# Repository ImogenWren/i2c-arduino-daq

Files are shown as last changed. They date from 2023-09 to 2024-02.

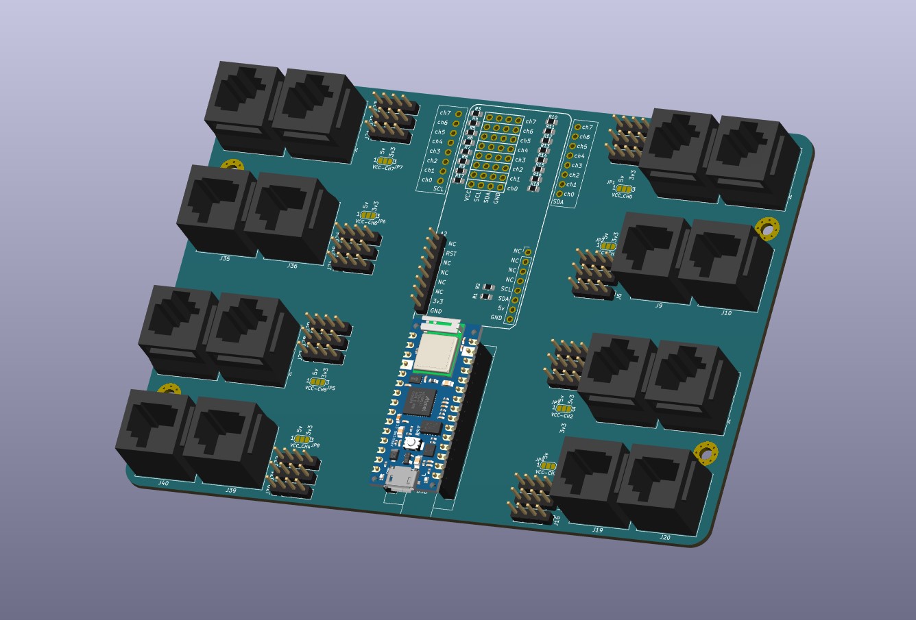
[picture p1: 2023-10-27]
i2c-sensor-breakout-pcb/euro-project-pcb-layout-one.jpg

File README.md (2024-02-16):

# i2c Sensor Breakout Board for Data Aquisition Tasks
Flexible system for gathering i2c sensor data and providing sources to Data Aquisition software (LabVIEW, Python, Matlab, Terra Term, etc)

_The included firmware shows how to wrap up any external sensor library into a flexible format that allows easy modification to existing system and easy addition of 
new sensors._

_PCB Developed for use with Senserion i2c sensors, though is compatable with any i2c enabled periferal devices_

- Data output in CSV format over USB Serial connection as MVP for communications or logging with external software
- Could be improved by the addition of ModBus or JSON formatted data communication with error checking

## PCB



## Hardware Required
- Arduino Nano (PCB designed for this footprint, but other Arduino boards are compatable)
	- SDA A4
	- SCL A5
	
- DAQ (Data AQuisition) PCB
- Logging software
- USB port

## Sensirion SCD41 - CO2 Sensor - i2c
 - 5v or 3.3v

## Sensirion SEK-STC31 - CO2 Sensor - i2c

- 5v or 3.3v (calibrated for 3.3v)

 - Pinout: 
	- Vdd: brown    green
	- SCL: green    brown
	- GND: pink 	pink
	- SDA: yellow	Yellow
 
# Everything LabView

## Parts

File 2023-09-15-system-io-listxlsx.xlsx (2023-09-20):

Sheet: ListOfPoweredComponents
Area | Area Code | Description | Component Type | Component Code | Number Installed | Supplier | Manufacturer | Link to product | Country | Model | Acquired/To Order | Cost [£] | Voltage In | AC/DC | Rated Power [W] | Signal/Current [A] | NC/NO/Latching | Note | How long [s] it receives power
Removal Area α | RAα | Fan adsorption | Fan | FADS | 1 | Farnell | SANYO DENKI | https://uk.farnell.com/sanyo-denki/9cra0412p4k03/fan-c-rotating-40x40x48mm-12v/dp/1907869 | Philippines | 9CRA0412P4K03 | Acquired | 53.172 | 12 | DC | 21.6 | 1.6 |  | 21.6 W rated; 1.6 A; Axial Fan | 540
Removal Area α | RAα | Fan desorption | Fan | FDES | 1 | Farnell | SANYO DENKI | https://uk.farnell.com/sanyo-denki/9cra0412p4k03/fan-c-rotating-40x40x48mm-12v/dp/1907869 | Philippines | 9CRA0412P4K03 | Acquired | 53.172 | 12 | DC | 21.6 | 1.6 |  | 21.6 W rated; 1.6 A; Axial Fan | 360
Removal Area α | RAα | Fan regeneration | Fan | FREG | 1 | Farnell | SANYO DENKI | https://uk.farnell.com/sanyo-denki/9cra0412p4k03/fan-c-rotating-40x40x48mm-12v/dp/1907869 | Philippines | 9CRA0412P4K03 | Acquired | 53.172 | 12 | DC | 21.6 | 1.6 |  | 21.6 W rated; 1.6 A; Axial Fan | 300
Removal Area α | RAα | Butterfly valve 1 before contactor | Butterfly Valve | BV1 | 1 | T7 Design | T7 Design | https://www.t7design.co.uk/electric-hvac-butterfly-valve-68a-ac6-54f.html | UK | Diameter 40mm | Acquired | 50 | 6-24 | DC | 12.00 | 1.0 |  | need a reversing polarity rocker switch to open and close | closing/opening time MAX 5s
Removal Area α | RAα | Buttrefly valve 2 after contactor | Butterfly Valve | BV2 | 1 | T7 Design | T7 Design | https://www.t7design.co.uk/electric-hvac-butterfly-valve-68a-ac6-54f.html | UK | Diameter 40mm | Acquired | 50 | 6-24 | DC | 12.00 | 1.0 |  | need a reversing polarity rocker switch to open and close | closing/opening time MAX 5s
Removal Area α | RAα | Buttrefly valve 3 for water collector adsorption | Butterfly Valve | BV3 | 1 | T7 Design | T7 Design | https://www.t7design.co.uk/electric-hvac-butterfly-valve-68a-ac6-54f.html | UK | Diameter 40mm | Acquired | 50 | 6-24 | DC | 12.00 | 1.0 |  | need a reversing polarity rocker switch to open and close | closing/opening time MAX 5s
Removal Area α | RAα | Buttrefly valve 4 for CO2 collector adsorption | Butterfly Valve | BV4 | 1 | T7 Design | T7 Design | https://www.t7design.co.uk/electric-hvac-butterfly-valve-68a-ac6-54f.html | UK | Diameter 40mm | Acquired | 50 | 6-24 | DC | 12.00 | 1.0 |  | In alternative to V2. Need a reversing polarity rocker switch to open and close | closing/opening time MAX 5s
Removal Area α | RAα | Buttrefly valve 5 for water collector desorption | Butterfly Valve | BV5 | 1 | T7 Design | T7 Design | https://www.t7design.co.uk/electric-hvac-butterfly-valve-68a-ac6-54f.html | UK | Diameter 14 mm* (3D printed) | To Print | 50 | 6-24 | DC | 12.00 | 1.0 |  | In alternative to V4. Need a reversing polarity rocker switch to open and close | closing/opening time MAX 5s
Removal Area α | RAα | Buttrefly valve 6 for CO2 collector desorption - connection with desorption trains | Butterfly Valve | BV6 | 1 | T7 Design | T7 Design | https://www.t7design.co.uk/electric-hvac-butterfly-valve-68a-ac6-54f.html | UK | Diameter 14 mm* (3D printed) | To Print | 50 | 6-24 | DC | 12.00 | 1.0 |  | In alternative to V1. Need a reversing polarity rocker switch to open and close | closing/opening time MAX 5s
Removal Area α | RAα | Substitution Butterfly valve for V3 | Butterfly Valve | BV7 | 1 | T7 Design | T7 Design | https://www.t7design.co.uk/electric-hvac-butterfly-valve-68a-ac6-54f.html | UK | Diameter 40mm | Ordered | 50 | 6-24 | DC | 12.00 | 1.0 |  | In alternative to V3. Need a reversing polarity rocker switch to open and close | closing/opening time MAX 5s
Removal Area α | RAα | Isolation Valve before Water Collector | Solenoid Valve | V2 | 1 | Duncan Rogers | ASCO | https://www.emerson.com/en-us/catalog/automation-solutions/fluid-control-pneumatics?fetchFacets=true | UK | 8210P095 | To Order |  | 10.4-26.4 | DC | 1.20 | 1.0 | NC | OPTIONAL.3/4"; Normally Closed (close when powered); 1.2W; Low Power ASCO Solenoid Valve -Electronically Enhanced Solenoid Valves- Next Gen Series; Internal Material FKM | 780
Removal Area α | RAα | Discharge Valve Water Collector | Solenoid Valve | V4 | 1 | Duncan Rogers | ASCO | https://www.emerson.com/en-us/catalog/automation-solutions/fluid-control-pneumatics?fetchFacets=true | UK | 8210P035 | To Order |  | 10.4-26.4 | DC | 1.20 | 1.0 | NO | OPTIONAL. 3/4"; Normally Open (open when powered); 1.2W; Low Power ASCO Solenoid Valve; Low Power ASCO Solenoid Valve -Electronically Enhanced Solenoid Valves- Next Gen Series; Internal Material FKM | 300
Removal Area α | RAα | Isolation Valve before CO2 Collector | Solenoid Valve | V1 | 1 | Duncan Rogers | ASCO | https://www.emerson.com/en-us/catalog/automation-solutions/fluid-control-pneumatics?fetchFacets=true | UK | 8210P095 | To Order |  | 10.4-26.4 | DC | 1.20 | 1.0 | NC | OPTIONAL. 3/4"; Normally Closed (close when powered); 1.2W; Low Power ASCO Solenoid Valve -Electronically Enhanced Solenoid Valves- Next Gen Series; Internal Material FKM | 780
Removal Area α | RAα | Connection Valve from CO2 Collector to compression trains | Solenoid Valve | V3 | 1 | Duncan Rogers | ASCO | https://www.emerson.com/en-us/catalog/automation-solutions/fluid-control-pneumatics?fetchFacets=true | UK | 8210P095 | To Order |  | 10.4-26.4 | DC | 1.20 | 1.0 | NC | OPTIONAL. 3/4"; Normally Closed (close when powered); 1.2W; Low Power ASCO Solenoid Valve -Electronically Enhanced Solenoid Valves- Next Gen Series; Internal Material FKM | 900
Compressor Train A | CTA | Fan compression | Fan | FCOMP | 1 | Farnell | SANYO DENKI | https://uk.farnell.com/sanyo-denki/9cra0412p4k03/fan-c-rotating-40x40x48mm-12v/dp/1907869 | Philippines | 9CRA0412P4K03 | Acquired | 53.172 | 12 | DC | 21.6 | 1.6 |  | 21.6 W rated; 1.6 A; Axial Fan
Compressor Train A | CTA | Equilibration Valve between Compressor 1 and 2 | Solenoid Valve | VCA1 | 1 | Duncan Rogers | ASCO | https://www.emerson.com/en-us/catalog/automation-solutions/fluid-control-pneumatics?fetchFacets=true | UK | 8210P095 | Acquired |  | 10.4-26.4 | DC | 1.20 | 1.0 | NC | 3/4"; Normally Closed (close when powered); 1.2W; Low Power ASCO Solenoid Valve -Electronically Enhanced Solenoid Valves- Next Gen Series; Internal Material FKM | 600
Compressor Train A | CTA | Discharge valve between Compressor 2 and Fan Compression | Solenoid Valve | VCA3 | 1 | Duncan Rogers | ASCO | https://www.emerson.com/en-us/catalog/automation-solutions/fluid-control-pneumatics?fetchFacets=true | UK | 8262R077 | Acquired |  | 10.4-26.4 | DC | 1.20 | 1.0 | NC | 1/8"; Normally Closed (close when powered); 1.2W; Low Power ASCO Solenoid Valve -Electronically Enhanced Solenoid Valves- Next Gen Series; Internal Material FKM | 1140
Compressor Train A | CTA | Discharge valve after Compressor 2 | Solenoid Valve | VCA5 | 1 | Duncan Rogers | ASCO | https://www.emerson.com/en-us/catalog/automation-solutions/fluid-control-pneumatics?fetchFacets=true | UK | 8262R129 | Acquired |  | 10.4-26.4 | DC | 1.20 | 1.0 | NO | 1/8"; Normally Open (open when powered); 1.2W; Low Power ASCO Solenoid Valve -Electronically Enhanced Solenoid Valves- Next Gen Series; Internal Material FKM | 60
Compressor Train A | CTA | Discharge valve Compression 1 | Butterfly Valve | VCA7 | 1 | T7 Design | T7 Design | https://www.t7design.co.uk/electric-hvac-butterfly-valve-68a-ac6-54f.html | UK | Diameter 14 mm* (3D printed) | To Print | 50 | 6-24 | DC | 12.00 | 1.0
Compressor Train B | CTB | Isolation Valve before Compressor 1 | Solenoid Valve | VCB1 | 1 | Duncan Rogers | ASCO | https://www.emerson.com/en-us/catalog/automation-solutions/fluid-control-pneumatics?fetchFacets=true | UK | 8210P095 | To Order |  | 10.4-26.4 | DC | 1.20 | 1.0 | NC | 3/4"; Normally Closed (close when powered); 1.2W; Low Power ASCO Solenoid Valve -Electronically Enhanced Solenoid Valves- Next Gen Series; Internal Material FKM | 600
Compressor Train B | CTB | Equilibriation Valve between Compressor 1 and 2 | Solenoid Valve | VCB3 | 1 | Duncan Rogers | ASCO | https://www.emerson.com/en-us/catalog/automation-solutions/fluid-control-pneumatics?fetchFacets=true | UK | 8262R077 | To Order |  | 10.4-26.4 | DC | 1.20 | 1.0 | NC | 1/8"; Normally Closed (close when powered); 1.2W; Low Power ASCO Solenoid Valve -Electronically Enhanced Solenoid Valves- Next Gen Series; Internal Material FKM | 1140
Compressor Train B | CTB | Discharge valve after Compressor 2 | Solenoid Valve | VCB5 | 1 | Duncan Rogers | ASCO | https://www.emerson.com/en-us/catalog/automation-solutions/fluid-control-pneumatics?fetchFacets=true | UK | 8262R129 | To Order |  | 10.4-26.4 | DC | 1.20 | 1.0 | NO | 1/8"; Normally Open (open when powered); 1.2W; Low Power ASCO Solenoid Valve -Electronically Enhanced Solenoid Valves- Next Gen Series; Internal Material FKM | 60
Compressor Train B | CTB | Discharge valve Compression 1 | Solenoid Valve | VCB7 | 1 | Duncan Rogers | ASCO | https://www.emerson.com/en-us/catalog/automation-solutions/fluid-control-pneumatics?fetchFacets=true | UK | 8210P035 | To Order |  | 10.4-26.4 | DC | 1.20 | 1.0 | NO | 3/4"; Normally Open (open when powered); 1.2W; Low Power ASCO Solenoid Valve; Low Power ASCO Solenoid Valve -Electronically Enhanced Solenoid Valves- Next Gen Series; Internal Material FKM | 60
Heating and Cooling | H&C | Pump water regenerative heat exchangers loop | Pump | PWR | 1 | RS COMPONENTS | RS | https://uk.rs-online.com/web/p/water-pumps/8170772 | UK | M510M; RS Stock Number 8170772 | To Order | 130.96 | 12 | DC | 15.0 | 1.0 |  | OPTIONAL. MAX 8litre/min; MAX 580mbar; Requires RS Eqi-V2M Brushless controller (RS Stock No. 125-3571, https://uk.rs-online.com/web/p/pump-controllers/1253571) | 360
Heating and Cooling | H&C | Pump Heating Water Loop | Pump | PWH | 1 | RS COMPONENTS | RS | https://uk.rs-online.com/web/p/water-pumps/8170772 | UK | M510M; RS Stock Number 8170772 | Acquired | 130.96 | 12 | DC | 15.0 | 1.0 |  | MAX 8litre/min; MAX 580mbar; Requires RS Eqi-V2M Brushless controller (RS Stock No. 125-3571, https://uk.rs-online.com/web/p/pump-controllers/1253571) | 360
Heating and Cooling | H&C | Pump Cooling Water Loop | Pump | PWC | 1 | RS COMPONENTS | RS | https://uk.rs-online.com/web/p/water-pumps/8170772 | UK | M510M; RS Stock Number 8170772 | To Order | 130.96 | 12 | DC | 15.0 | 1.0 |  | MAX 8litre/min; MAX 580mbar; Requires RS Eqi-V2M Brushless controller (RS Stock No. 125-3571, https://uk.rs-online.com/web/p/pump-controllers/1253571) | 360
Heating and Cooling | H&CA | Pump Thermal Wave 1 | Pump | PTWA | 1 | RS COMPONENTS | RS | https://uk.rs-online.com/web/p/water-pumps/8170772 | UK | M510M; RS Stock Number 8170772 | To Order | 130.96 | 12 | DC | 15.0 | 1.0 |  | MAX 8litre/min; MAX 580mbar; Requires RS Eqi-V2M Brushless controller (RS Stock No. 125-3571, https://uk.rs-online.com/web/p/pump-controllers/1253571) | 1200
Heating and Cooling | H&CA | Solenoid Valve Thermal Wave 1 | Solenoid Valve | VTWA1 | 1 | CONNEXION DEVELOPMENTS LTD | RPE Srl | https://solenoid-valve.world/product/898/rpe-srl/8mm-push-fit-water-solenoid-valve-02-10bar-nylon-6v-latching-1145bb | Italy | 1145BB | To Order | 35.5 | 12 | DC | 2.25 | 0.375 | Latching | 6 or 12vDC 2.25Watts 375mA
Heating and Cooling | H&CA | Solenoid Valve Thermal Wave 2 | Solenoid Valve | VTWA2 | 1 | CONNEXION DEVELOPMENTS LTD | RPE Srl | https://solenoid-valve.world/product/898/rpe-srl/8mm-push-fit-water-solenoid-valve-02-10bar-nylon-6v-latching-1145bb | Italy | 1145BB | To Order | 35.5 | 12 | DC | 2.25 | 0.375 | Latching | 6 or 12vDC 2.25Watts 375mA
Heating and Cooling | H&CA | Solenoid Valve Thermal Wave 3 | Solenoid Valve | VTWA3 | 1 | CONNEXION DEVELOPMENTS LTD | RPE Srl | https://solenoid-valve.world/product/898/rpe-srl/8mm-push-fit-water-solenoid-valve-02-10bar-nylon-6v-latching-1145bb | Italy | 1145BB | To Order | 35.5 | 12 | DC | 2.25 | 0.375 | Latching | 6 or 12vDC 2.25Watts 375mA
Heating and Cooling | H&CA | Solenoid Valve Thermal Wave 4 | Solenoid Valve | VTWA4 | 1 | CONNEXION DEVELOPMENTS LTD | RPE Srl | https://solenoid-valve.world/product/898/rpe-srl/8mm-push-fit-water-solenoid-valve-02-10bar-nylon-6v-latching-1145bb | Italy | 1145BB | To Order | 35.5 | 12 | DC | 2.25 | 0.375 | Latching | 6 or 12vDC 2.25Watts 375mA
Heating and Cooling | H&CB | Pump Thermal Wave 1 | Pump | PTWB | 1 | RS COMPONENTS | RS | https://uk.rs-online.com/web/p/water-pumps/8170772 | UK | M510M; RS Stock Number 8170772 | To Order | 130.96 | 12 | DC | 15.0 | 1.0 |  | MAX 8litre/min; MAX 580mbar; Requires RS Eqi-V2M Brushless controller (RS Stock No. 125-3571, https://uk.rs-online.com/web/p/pump-controllers/1253571) | 1200
Heating and Cooling | H&CB | Solenoid Valve Thermal Wave 1 | Solenoid Valve | VTWB1 | 1 | CONNEXION DEVELOPMENTS LTD | RPE Srl | https://solenoid-valve.world/product/898/rpe-srl/8mm-push-fit-water-solenoid-valve-02-10bar-nylon-6v-latching-1145bb | Italy | 1145BB | To Order | 35.5 | 12 | DC | 2.25 | 0.375 | Latching | 6 or 12vDC 2.25Watts 375mA
Heating and Cooling | H&CB | Solenoid Valve Thermal Wave 2 | Solenoid Valve | VTWB2 | 1 | CONNEXION DEVELOPMENTS LTD | RPE Srl | https://solenoid-valve.world/product/898/rpe-srl/8mm-push-fit-water-solenoid-valve-02-10bar-nylon-6v-latching-1145bb | Italy | 1145BB | To Order | 35.5 | 12 | DC | 2.25 | 0.375 | Latching | 6 or 12vDC 2.25Watts 375mA
Heating and Cooling | H&CB | Solenoid Valve Thermal Wave 3 | Solenoid Valve | VTWB3 | 1 | CONNEXION DEVELOPMENTS LTD | RPE Srl | https://solenoid-valve.world/product/898/rpe-srl/8mm-push-fit-water-solenoid-valve-02-10bar-nylon-6v-latching-1145bb | Italy | 1145BB | To Order | 35.5 | 12 | DC | 2.25 | 0.375 | Latching | 6 or 12vDC 2.25Watts 375mA
Heating and Cooling | H&CB | Solenoid Valve Thermal Wave 4 | Solenoid Valve | VTWB4 | 1 | CONNEXION DEVELOPMENTS LTD | RPE Srl | https://solenoid-valve.world/product/898/rpe-srl/8mm-push-fit-water-solenoid-valve-02-10bar-nylon-6v-latching-1145bb | Italy | 1145BB | To Order | 35.5 | 12 | DC | 2.25 | 0.375 | Latching | 6 or 12vDC 2.25Watts 375mA
 |  |  | Total Digital Out | 35 |  |  |  |  |  |  |  |  |  |  | 288.6 | 33.4
 |  |  |  |  |  |  |  |  |  |  |  |  |  |  | Power Needed | Current Needed

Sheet: ListOfSensors
Area | Area Code | Description | Component Type | Component Code | DAQ Module | Channel | Units Installed | Supplier | Manufacturer | Link to product | Country | Model | Acquired/To Order | Cost [£] | Voltage In [V] | Current In [mA] | AC/DC | MAX Power [W] | Analogue/Digital | Signal Type | Signal Range | Note
Removal Area α | RAα | ΔP Sensor across FADS | Pressure Differential Sensor | ΔP1 | NI 9201 B | 0 | 1 | Farnell | Sensirion | https://uk.farnell.com/sensirion/sdp816-125pa/pressure-sensor-analogue-125pa/dp/2886667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 | Switzerland | SDP816-125PA | Acquired | 28.4 | 2.7-5.5 | 0.0055 | DC | 0.03025 | Analogue Ratiometric | Voltage | 10%-90% of Supply Voltage
Removal Area α | RAα | ΔP Sensor across FDES | Pressure Differential Sensor | ΔP2 | NI 9201 B | 1 | 1 | Farnell | Sensirion | https://uk.farnell.com/sensirion/sdp816-500pa/pressure-sensor-analogue-500pa/dp/2886668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 | Switzerland | SDP816-500PA | Acquired | 28.4 | 2.7-5.5 | 0.0055 | DC | 0.03025 | Analogue Ratiometric | Voltage | 10%-90% of Supply Voltage
Removal Area α | RAα | ΔP Sensor across FREG | Pressure Differential Sensor | ΔP3 | NI 9201 B | 2 | 1 | Farnell | Sensirion | https://uk.farnell.com/sensirion/sdp816-500pa/pressure-sensor-analogue-500pa/dp/2886668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 | Switzerland | SDP816-500PA | Acquired | 28.4 | 2.7-5.5 | 0.0055 | DC | 0.03025 | Analogue Ratiometric | Voltage | 10%-90% of Supply Voltage
Removal Area α | RAα | CO2, RH and T sensor before contactor | Carbon Dioxide, Relative Humidity and Temperature Sensor | CD1 | NI 9402 |  | 1 | Farnell | Sensirion | https://uk.farnell.com/sensirion/sek-scd41-sensor/development-board-co2-sensor/dp/3677907?ost=sek-scd+41 | Switzerland | SEK-SCD41 | Aquired | 103 | 2.4-5.5 |  | DC |  | Digital |  |  | I2C communication protocol
Removal Area α | RAα | CO2, RH and T sensor after contactor | Carbon Dioxide, Relative Humidity and Temperature Sensor | CD2 | NI 9402 |  | 1 | Farnell | Sensirion | https://uk.farnell.com/sensirion/sek-scd41-sensor/development-board-co2-sensor/dp/3677907?ost=sek-scd+41 | Switzerland | SEK-SCD41 | Aquired | 103 | 2.4-5.5 |  | DC |  | Digital |  |  | I2C communication protocol
Removal Area α | RAα | CO2 Sensor before collectors | Carbon Dioxide Sensor | CD3 | NI 9402 | ? | 1 | Farnell | Sensirion | https://uk.farnell.com/sensirion/sek-stc31/eval-kit-co2-sensor/dp/3804234?st=co2%20sensor | Switzerland | SEK-STC31 | To Order | 59.7 | 3.3 | 0.005 | DC | 0.03025 | Digital |  |  | I2C communication protocol
Removal Area α | RAα | CO2 Sensor after collectors | Carbon Dioxide Sensor | CD4 | NI 9402 | ? | 1 | Farnell | Sensirion | https://uk.farnell.com/sensirion/sek-stc31/eval-kit-co2-sensor/dp/3804234?st=co2%20sensor | Switzerland | SEK-STC31 | To Order | 59.7 | 3.3 | 0.005 | DC | 0.03025 | Digital |  |  | I2C communication protocol
Removal Area α | RAα | CO2 Sensor after water collector | Carbon Dioxide Sensor | CD5 | NI 9402 | ? | 1 | Farnell | Sensirion | https://uk.farnell.com/sensirion/sek-stc31/eval-kit-co2-sensor/dp/3804234?st=co2%20sensor | Switzerland | SEK-STC31 | To Order | 59.7 | 3.3 | 0.005 | DC | 0.03025 | Digital |  |  | I2C communication protocol
Removal Area α | RAα | CO2 Sensor after CO2 collector | Carbon Dioxide Sensor | CD6 | NI 9402 | ? | 1 | Farnell | Sensirion | https://uk.farnell.com/sensirion/sek-stc31/eval-kit-co2-sensor/dp/3804234?st=co2%20sensor | Switzerland | SEK-STC31 | To Order | 59.7 | 3.3 | 0.005 | DC | 0.03025 | Digital |  |  | I2C communication protocol
Removal Area α | RAα |  | Relative Humidity and Temperature Sensor | RHT1 | NI 9402 | ? | 1 | Farnell | Sensirion | https://uk.farnell.com/sensirion/sek-sht45-ad1b-sensors/evaluation-kit-temp-humidity-sensor/dp/3958229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 | Switzerland | SEK-SHT45 | Ordered | 32.3 | 1.08-3.6 | 0.002 | DC | 0.2 | Digital |  |  | I2C communication protocol; Each SEK-SHT45 contains 3 sensors but needs the SEK sensor bridge
Removal Area α | RAα |  | Relative Humidity and Temperature Sensor | RHT2 | NI 9402 | ? | 1 | RS | Sensirion | https://uk.rs-online.com/web/p/sensor-development-tools/2365204 | Switzerland | SEK-SHT41I-AD1B | Ordered | 37.47 | 2.3-5.5 | 0.002 | DC | 0.2 | Digital |  |  | I2C communication protocol; Each SEK-SHT41I contains 3 sensors but needs the SEK sensor bridge
Removal Area α | RAα | RH and T Sensor before collectors | Relative Humidity and Temperature Sensor | RHT3 | NI 9402 | ? | 1 | RS | Sensirion | https://uk.rs-online.com/web/p/sensor-development-tools/2365204 | Switzerland | SEK-SHT41I-AD1B | Ordered | 37.47 | 2.3-5.5 | 0.002 | DC | 0.2 | Digital |  |  | I2C communication protocol; Each SEK-SHT41I contains 3 sensors but needs the SEK sensor bridge
Removal Area α | RAα | RH and T Sensor after collectors | Relative Humidity and Temperature Sensor | RHT4 | NI 9402 | ? | 1 | RS | Sensirion | https://uk.rs-online.com/web/p/sensor-development-tools/2365204 | Switzerland | SEK-SHT41I-AD1B | Ordered | 37.47 | 2.3-5.5 | 0.002 | DC | 0.2 | Digital |  |  | I2C communication protocol; Each SEK-SHT41I contains 3 sensors but needs the SEK sensor bridge
Removal Area α | RAα | RH and T Sensor after water collector | Relative Humidity and Temperature Sensor | RHT5 | NI 9402 | ? | 1 | RS | Sensirion | https://uk.rs-online.com/web/p/sensor-development-tools/2365204 | Switzerland | SEK-SHT41I-AD1B | Ordered | 37.47 | 2.3-5.5 | 0.002 | DC | 0.2 | Digital |  |  | I2C communication protocol; Each SEK-SHT41I contains 3 sensors but needs the SEK sensor bridge
Removal Area α | RAα | RH and T Sensor after CO2 collector | Relative Humidity and Temperature Sensor | RHT6 | NI 9402 | ? | 1 | RS | Sensirion | https://uk.rs-online.com/web/p/sensor-development-tools/2365204 | Switzerland | SEK-SHT41I-AD1B | Ordered | 37.47 | 2.3-5.5 | 0.002 | DC | 0.2 | Digital |  |  | I2C communication protocol; Each SEK-SHT41I contains 3 sensors but needs the SEK sensor bridge
Removal Area α | RAα | Current Tranducer FADS | Curent Sensor | CS1 | NI 9201 A | 0 | 1 |  | Seedstudio |  |  |  | Aquired | 5 | 3.3-5 |  | DC | 0.027 | Analogue proportional to current | Voltage |  | ±5A DC/AC Current Sensor; base sensitivity of 200mV/A (approx); | 0-1v
Removal Area α | RAα |  | Curent Sensor | CS1 | NI 9201 A | 0 | 1 | RS/ACTIVE ROBOT | Allegro | https://uk.rs-online.com/web/p/current-sensor-ics/8660767 or https://www.active-robots.com/sparkfun-current-sensor-breakout-acs723-low-current.html |  | ACS723LLCTR-05AB-T or in SparkFun Current Sensor Breakout - ACS723 (Low Current) | Ordered | 5 | 4.5-5.5 | 0.006 | DC | 0.027 | Analogue proportional to current | Voltage |  | ±5A DC/AC Current Sensor; base sensitivity of 200mV/A (approx); Requires a microprocessor board; | 0-1v
Removal Area α | RAα | Current Tranducer FDES | Curent Sensor | CS2 | NI 9201 A | 0 | 1 |  | Seedstudio |  |  |  | Aquired | 5 | 3.3-5 |  | DC | 0.027 | Analogue proportional to current | Voltage |  | ±5A DC/AC Current Sensor; base sensitivity of 200mV/A (approx); | 0-1v
Removal Area α | RAα |  | Curent Sensor | CS2 | NI 9201 A | 1 | 1 | RS/ACTIVE ROBOT | Allegro | https://uk.rs-online.com/web/p/current-sensor-ics/8660767 or https://www.active-robots.com/sparkfun-current-sensor-breakout-acs723-low-current.html |  | ACS723LLCTR-05AB-T or in SparkFun Current Sensor Breakout - ACS723 (Low Current) | Ordered | 5 | 4.5-5.5 | 0.006 | DC | 0.027 | Analogue proportional to current | Voltage |  | ±5A DC/AC Current Sensor; base sensitivity of 400mV/A (approx); Requires a microprocessor board; | 0-1v
Removal Area α | RAα | Current Tranducer FREG | Curent Sensor | CS3 | NI 9201 A | 2 | 1 | RS/ACTIVE ROBOT | Allegro | https://uk.rs-online.com/web/p/current-sensor-ics/8660767 or https://www.active-robots.com/sparkfun-current-sensor-breakout-acs723-low-current.html |  | ACS723LLCTR-05AB-T or in SparkFun Current Sensor Breakout - ACS723 (Low Current) | Ordered | 5 | 4.5-5.5 | 0.006 | DC | 0.027 | Analogue proportional to current | Voltage |  | ±5A DC/AC Current Sensor; base sensitivity of 400mV/A (approx); Requires a microprocessor board; | 0-1v
Removal Area α | RAα | T probe before HEXC-AIR | Thermocouple | T1 | NI 9213 A | 0 | 1 | Farnell | Omega | https://at.farnell.com/en-AT/omega/htmtss-125g-6/thermoelement-typ-t-152-4mm-315/dp/3799164 | United States | HTMTSS-125G-6 | Acquired |  |  |  |  |  |  |  |  | T thermocouple
Removal Area α | RAα |  | Thermocouple | T2 | NI 9213 A | 1 |  |  |  |  |  |  | Acquired |  |  |  |  |  |  |  |  | T thermocouple
Removal Area α | RAα | T probe after HEXC-AIR | Thermocouple | T3 | NI 9213 A | 2 | 1 | Farnell | Omega | https://at.farnell.com/en-AT/omega/htmtss-125g-6/thermoelement-typ-t-152-4mm-315/dp/3799164 | United States | HTMTSS-125G-6 | Acquired |  |  |  |  |  |  |  |  | T thermocouple
Removal Area α | RAα | T probe before HEXH-AIR | Thermocouple | T4 | NI 9213 A | 3 | 1 | Farnell | Omega | https://at.farnell.com/en-AT/omega/htmtss-125g-6/thermoelement-typ-t-152-4mm-315/dp/3799164 | United States | HTMTSS-125G-6 | Acquired |  |  |  |  |  |  |  |  | T thermocouple
Removal Area α | RAα |  | Thermocouple | T5 | NI 9213 A | 4 |  |  |  |  |  |  | Acquired |  |  |  |  |  |  |  |  | Optional. T thermocouple
Removal Area α | RAα | T probe after HEXH-AIR | Thermocouple | T6 | NI 9213 A | 5 | 1 | Farnell | Omega | https://at.farnell.com/en-AT/omega/htmtss-125g-6/thermoelement-typ-t-152-4mm-315/dp/3799164 | United States | HTMTSS-125G-6 | Acquired |  |  |  |  |  |  |  |  | T thermocouple
Removal Area α | RAα | T probe HEXC-WATER in | Thermocouple | TR1 | NI 9213 A | 6 | 1 | RS |  | RS PRO Type K Thermocouple 250mm Length, 3mm Diameter → +1100°C | RS (rs-online.com) (https://uk.rs-online.com/web/p/thermocouples/3971270?gb=s) |  | 397-1270 | Ordered | 28.52 |  |  |  |  |  |  |  | T thermocouple
Removal Area α | RAα | T probe HEXC-WATER out | Thermocouple | TR2 | NI 9213 A | 7 | 1 | RS |  | RS PRO Type K Thermocouple 250mm Length, 3mm Diameter → +1100°C | RS (rs-online.com) (https://uk.rs-online.com/web/p/thermocouples/3971270?gb=s) |  | 397-1270 | Ordered | 28.52 |  |  |  |  |  |  |  | T thermocouple
Removal Area α | RAα | T probe HEXH-WATER in | Thermocouple | TR3 | NI 9213 A | 8 | 1 | RS |  | RS PRO Type K Thermocouple 250mm Length, 3mm Diameter → +1100°C | RS (rs-online.com) (https://uk.rs-online.com/web/p/thermocouples/3971270?gb=s) |  | 397-1270 | Ordered | 28.52 |  |  |  |  |  |  |  | T thermocouple
Removal Area α | RAα | T probe HEXH-WATER out | Thermocouple | TR4 | NI 9213 A | 9 | 1 | RS |  | RS PRO Type K Thermocouple 250mm Length, 3mm Diameter → +1100°C | RS (rs-online.com) (https://uk.rs-online.com/web/p/thermocouples/3971270?gb=s) |  | 397-1270 | Ordered | 28.52 |  |  |  |  |  |  |  | T thermocouple
Compressor Train A | CTA | CO2 Sensor before COMPA1 | Carbon Dioxide Sensor | CDCA1
Compressor Train A | CTA | RH and T Sensor before COMPA1 | Relative Humidity and Temperature Sensor | RHTCA1 |  |  |  |  |  |  |  |  | Acquired
Compressor Train A | CTA | CO2, RH and T sensor before COMPA 2 | Carbon Dioxide, Relative Humidity and Temperature Sensor | CDCA2 |  |  |  | RS | Sensirion | https://uk.rs-online.com/web/p/temperature-humidity-sensor-ics/1720552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 |  |  | Acquired
Compressor Train A | CTA | CO2, RH and T sensor out system | Carbon Dioxide, Relative Humidity and Temperature Sensor | CDCA3 |  |  |  | RS | Sensirion | https://uk.rs-online.com/web/p/temperature-humidity-sensor-ics/1720552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 |  |  | Acquired
Compressor Train A | CTA | T probe after COMPA1 | Thermocouple | TCA1
Compressor Train A | CTA | T probe after COMPA2 | Thermocouple | TCA2
Compressor Train A | CTA | T probe HEXC-WATER in | Thermocouple | TRCA1
Compressor Train A | CTA | T probe HEXC-WATER out | Thermocouple | TRCA2
Compressor Train A | CTA | T probe HEXH-WATER in | Thermocouple | TRCA3
Compressor Train A | CTA | T probe HEXH-WATER out | Thermocouple | TRCA4
Compressor Train A | CTA | Pressure Transducer COMPA1 | Preussure Transducer Compressor A1 | PCA1 | NI 9201 B | 3 | 1 | JWF Process Solutions | WIKA | https://www.wika.com/en-gb/s_20.WIKA?36404=36404_0&36405=36405_0&36406=36406_0&36407=36407_0 |  | A-10 | Ordered | 137 | 8-30 | 0.02 | DC | 0.6 | Analogue | 0-10 V
Compressor Train A | CTA | Pressure Transducer COMPA2 | Preussure Transducer Compressor A2 | PCA2 | NI 9201 B | 4 | 1 | JWF Process Solutions | WIKA | https://www.wika.com/en-gb/s_20.WIKA?36404=36404_0&36405=36405_0&36406=36406_0&36407=36407_0 |  | A-10 | Ordered | 137 | 8-30 | 0.02 | DC | 0.6 | Analogue | 0-10 V
Compressor Train A | CTA | RH and T sensor after COMPA1 | Relative Humidity and Temperature Sensor | CARTH1 | NI 9402 | ? | 1 | Farnell | Sensirion | https://uk.farnell.com/sensirion/sek-sht45-ad1b-sensors/evaluation-kit-temp-humidity-sensor/dp/3958229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 | Switzerland | SEK-SHT41I-AD1B | Ordered | 37.5 | 1.08-3.6 | 0.002 | DC | 0.2 | Digital |  |  | I2C communication protocol; Each SEK-SHT45 contains 3 sensors but needs the SEK sensor bridge
Compressor Train A | CTA | CO2 Sensor after COMPA1 | Carbon Dioxide Sensor | CACD1 | NI 9402 | ? | 1 | RS Components | Sensirion | https://uk.rs-online.com/web/p/sensor-development-tools/2365204 | Switzerland | SEK-STC31 | To Order | 59.7 | 3.3 | 0.005 | DC | 0.03025 | Digital |  |  | I2C communication protocol
Compressor Train B | CTB | Pressure Transducer COMPB1 | Preussure Transducer Compressor B1 | PCB1 | NI 9201 B | 5 | 1 | JWF Process Solutions | WIKA | https://www.wika.com/en-gb/s_20.WIKA?36404=36404_0&36405=36405_0&36406=36406_0&36407=36407_0 |  | A-10 | Ordered | 137 | 8-30 | 0.02 | DC | 0.6 | Analogue | 0-10 V
Compressor Train B | CTB | Pressure Transducer COMPB2 | Preussure Transducer Compressor B2 | PCB2 | NI 9201 B | 6 | 1 | JWF Process Solutions | WIKA | https://www.wika.com/en-gb/s_20.WIKA?36404=36404_0&36405=36405_0&36406=36406_0&36407=36407_0 |  | A-10 | Ordered | 137 | 8-30 | 0.02 | DC | 0.6 | Analogue | 0-10 V
Compressor Train B | CTB | RH and T sensor after COMPB1 | Relative Humidity and Temperature Sensor | CBRTH1 | NI 9402 | ? | 1 | RS Components | Sensirion | https://uk.rs-online.com/web/p/sensor-development-tools/2365204 | Switzerland | SEK-SHT41I-AD1B | Ordered | 37.5 | 1.08-3.6 | 0.002 | DC | 0.2 | Digital |  |  | I2C communication protocol; Each SEK-SHT45 contains 3 sensors but needs the SEK sensor bridge
Compressor Train B | CTB | CO2 Sensor after COMPB1 | Carbon Dioxide Sensor | CBCD1 | NI 9402 | ? | 1 | Farnell | Sensirion | https://uk.farnell.com/sensirion/sek-stc31/eval-kit-co2-sensor/dp/3804234?st=co2%20sensor | Switzerland | SEK-STC31 | To Order | 59.7 | 3.3 | 0.005 | DC | 0.03025 | Digital |  |  | I2C communication protocol
Supply Area | SA | Pressure Transducer GST | Preussure Transducer CO2 Storage | PC | NI 9201 B | 7 | 1 | JWF Process Solutions | WIKA | https://www.wika.com/en-gb/s_20.WIKA?36404=36404_0&36405=36405_0&36406=36406_0&36407=36407_0 |  | A-10 | Ordered | 137 | 8-30 | 0.02 | DC | 0.6 | Analogue | 0-10 V
Supply Area | SA | T probe in GST | Thermocouple in the CO2 Storage | TC | NI 9213 B | 8 | 1 | ESTech Lab | ESTech Lab |  |  |  | Acquired |  |  |  |  |  |  |  |  | T thermocouple
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

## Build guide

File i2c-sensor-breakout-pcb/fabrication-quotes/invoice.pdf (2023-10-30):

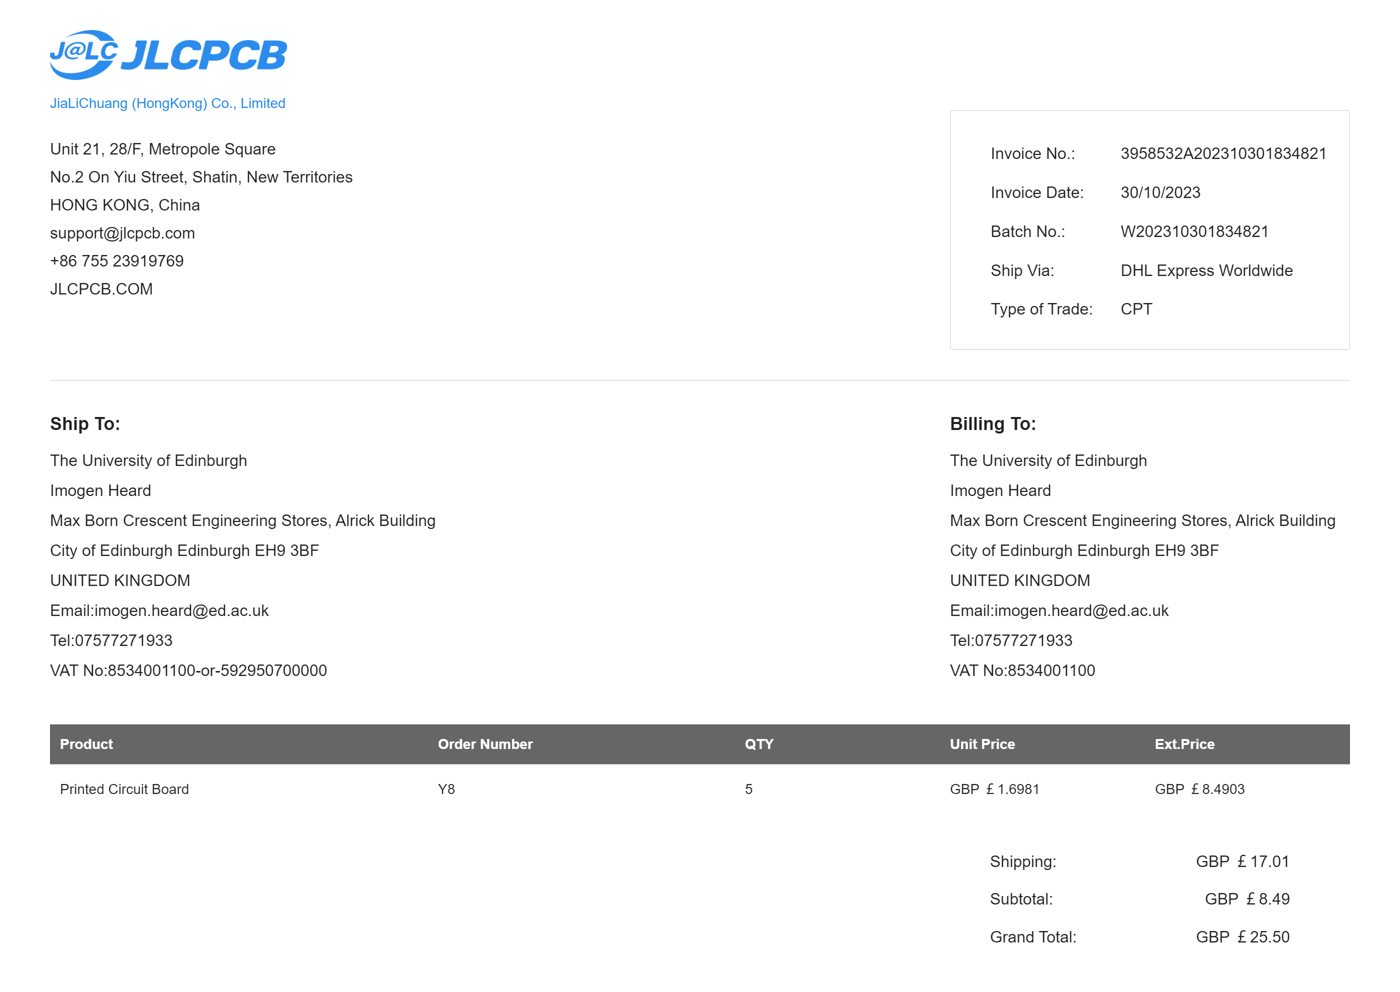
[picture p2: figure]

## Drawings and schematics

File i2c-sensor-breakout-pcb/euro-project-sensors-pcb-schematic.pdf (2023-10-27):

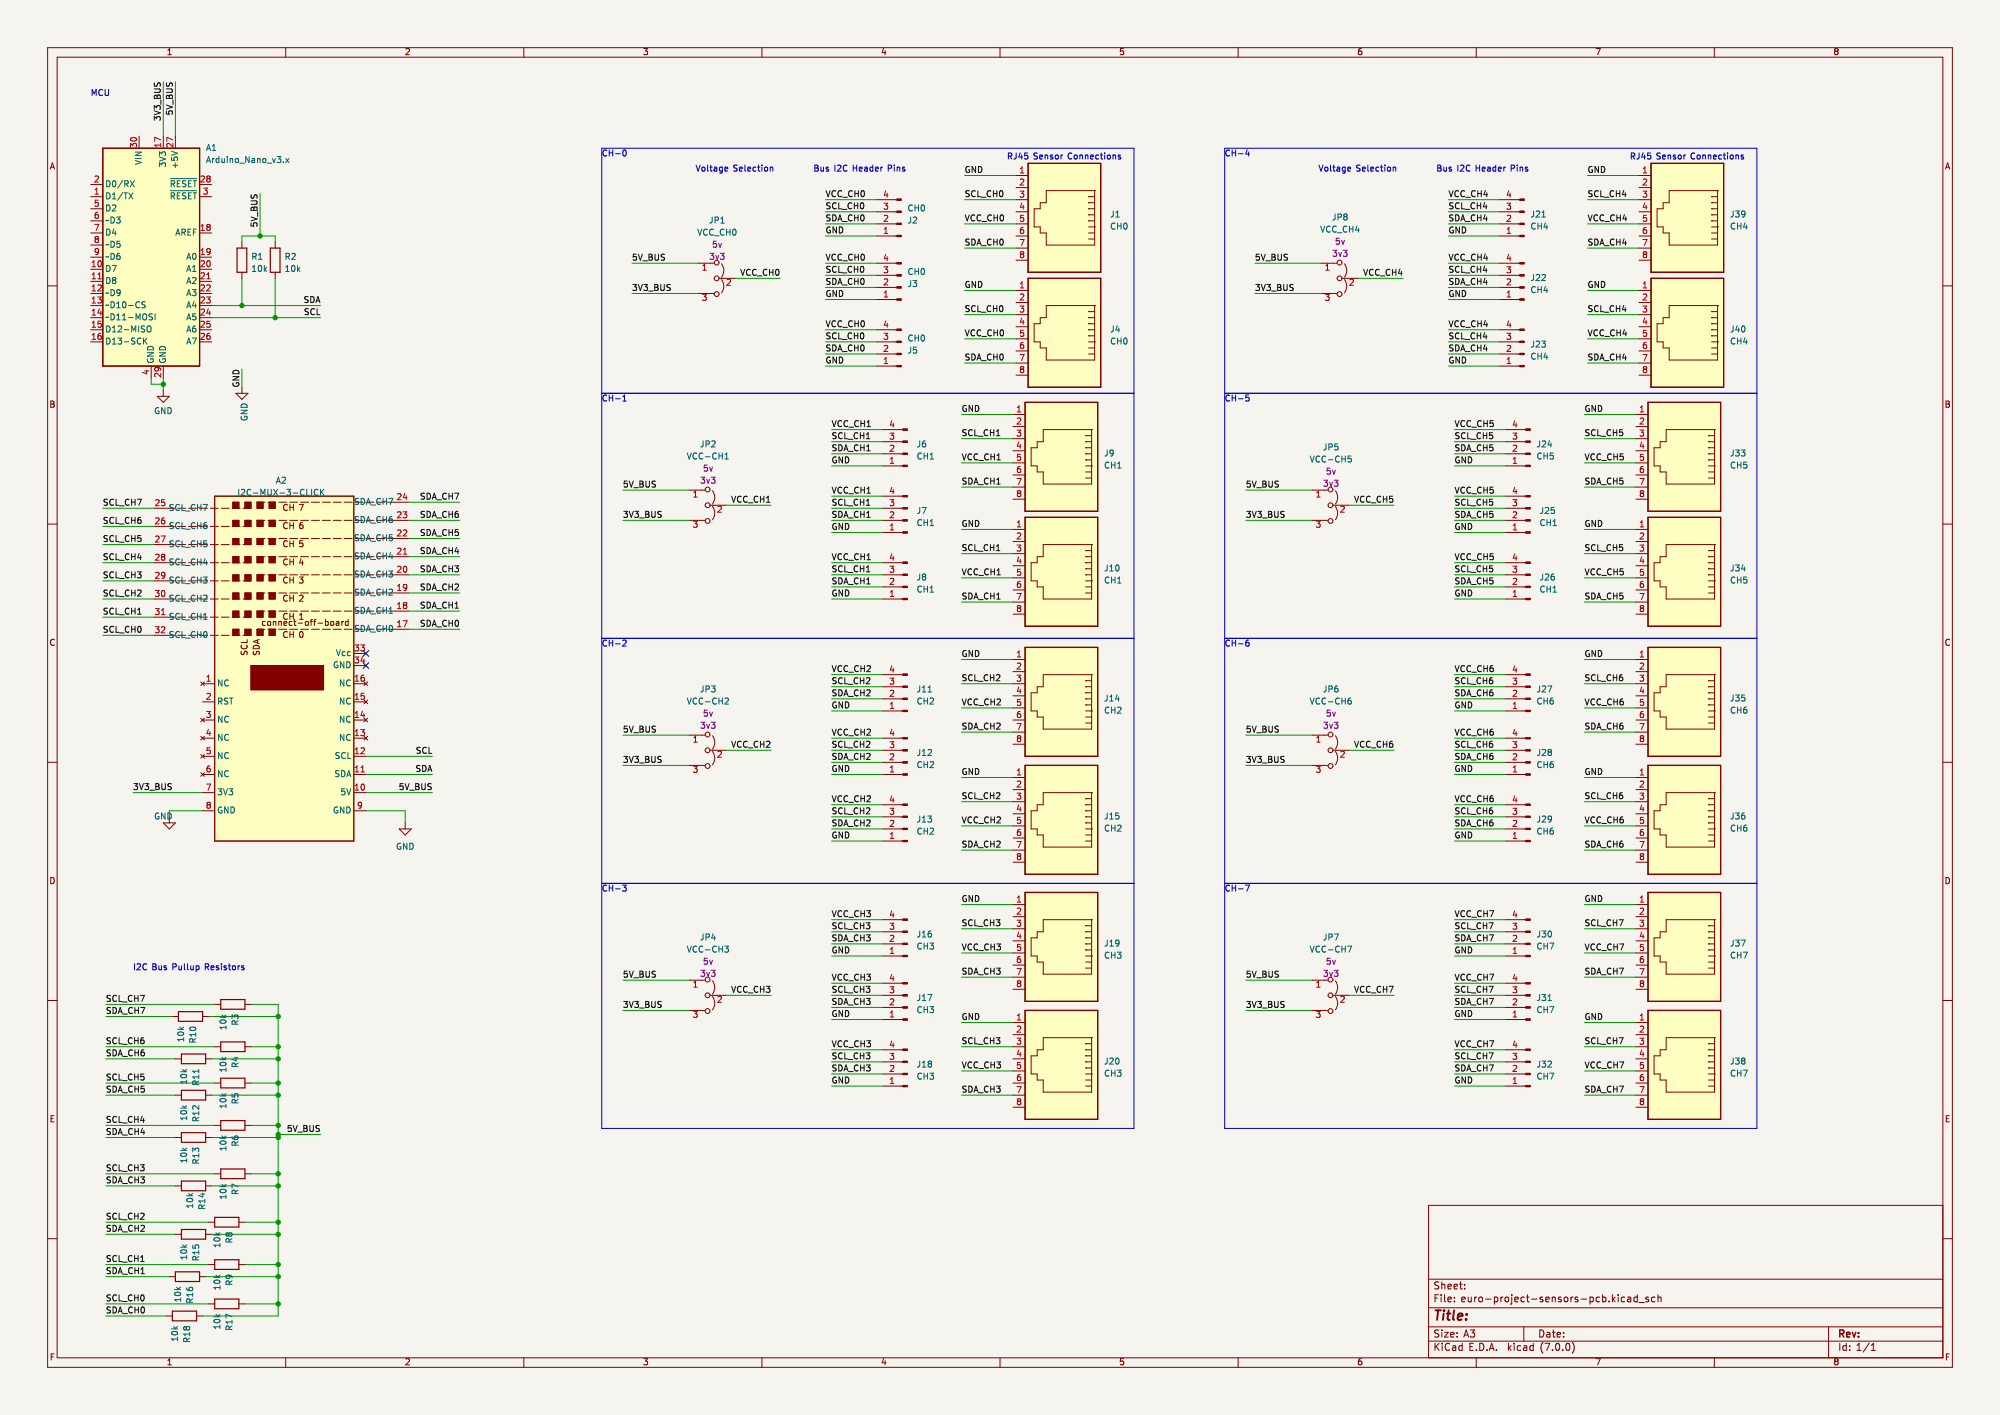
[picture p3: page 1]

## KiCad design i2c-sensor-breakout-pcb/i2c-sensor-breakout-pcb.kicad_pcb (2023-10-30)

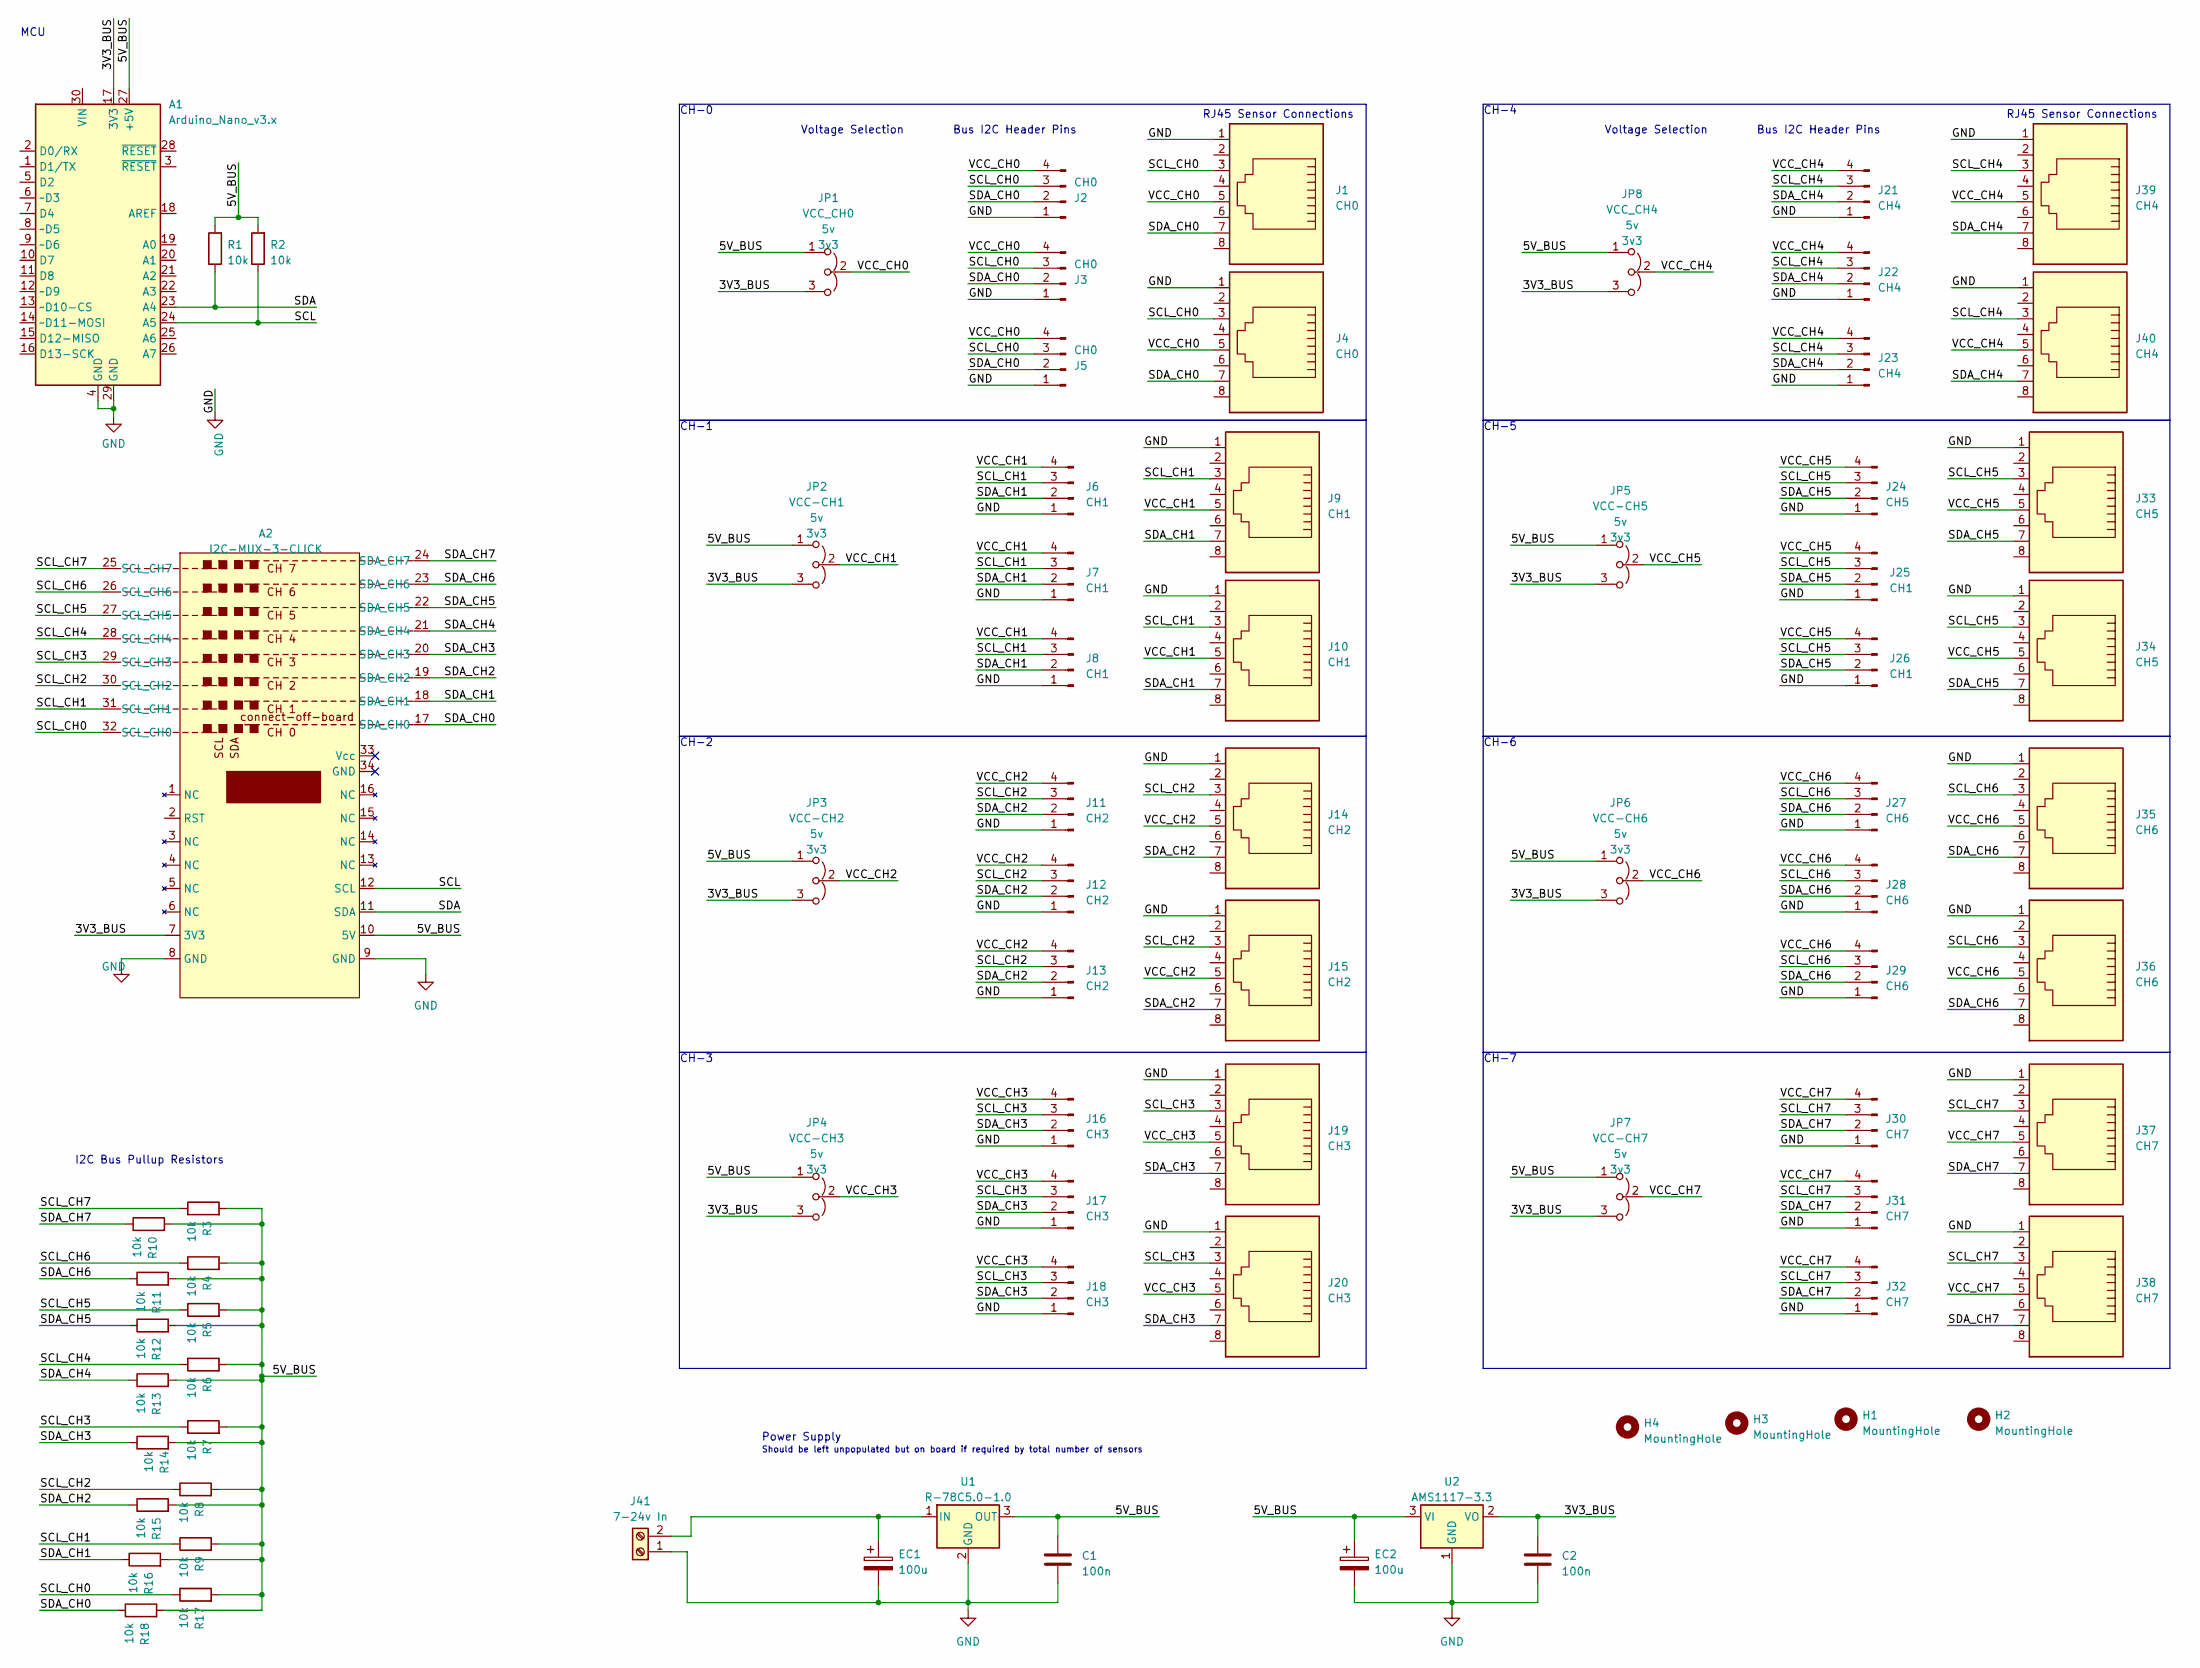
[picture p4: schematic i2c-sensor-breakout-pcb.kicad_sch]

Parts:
A1: Arduino_Nano_v3.x; Arduino_Nano
A2: I2C-MUX-3-CLICK
C1, C2: 100n; C_0805_2012_HandSolder_kawaii; JLCpart C779975
EC1, EC2: 100u; CP_Elec_10x10
H1, H2, H3, H4: MountingHole; MountingHole_3.2mm_M3_Pad_Via
J1, J4: CH0; RJ45_OST_PJ012-8P8CX_Vertical
J2, J3, J5: CH0; PinHeader_1x04_P2.54mm_Vertical
J6, J7, J8, J25, J26: CH1; PinHeader_1x04_P2.54mm_Vertical
J9, J10: CH1; RJ45_OST_PJ012-8P8CX_Vertical
J11, J12, J13: CH2; PinHeader_1x04_P2.54mm_Vertical
J14, J15: CH2; RJ45_OST_PJ012-8P8CX_Vertical
J16, J17, J18: CH3; PinHeader_1x04_P2.54mm_Vertical
J19, J20: CH3; RJ45_OST_PJ012-8P8CX_Vertical
J21, J22, J23: CH4; PinHeader_1x04_P2.54mm_Vertical
J24: CH5; PinHeader_1x04_P2.54mm_Vertical
J27, J28, J29: CH6; PinHeader_1x04_P2.54mm_Vertical
J30, J31, J32: CH7; PinHeader_1x04_P2.54mm_Vertical
J33, J34: CH5; RJ45_OST_PJ012-8P8CX_Vertical
J35, J36: CH6; RJ45_OST_PJ012-8P8CX_Vertical
J37, J38: CH7; RJ45_OST_PJ012-8P8CX_Vertical
J39, J40: CH4; RJ45_OST_PJ012-8P8CX_Vertical
J41: 7-24v In; TerminalBlock_Altech_AK300-2_P5.00mm; JLCpart C918120
JP1: VCC_CH0; SolderJumper-3-open-high-power
JP2: VCC-CH1; SolderJumper-3-open-high-power
JP3: VCC-CH2; SolderJumper-3-open-high-power
JP4: VCC-CH3; SolderJumper-3-open-high-power
JP5: VCC-CH5; SolderJumper-3-open-high-power
JP6: VCC-CH6; SolderJumper-3-open-high-power
JP7: VCC-CH7; SolderJumper-3-open-high-power
JP8: VCC_CH4; SolderJumper-3-open-high-power
R1, R2, R3, R4, R5, R6, R7, R8, R9, R10, R11, R12, R13, R14, R15, R16, R17, R18: 10k; R_0805_2012Metric_Pad1.20x1.40mm_HandSolder; JLCpart C2930231
U1: R-78C5.0-1.0; Converter_DCDC_RECOM_R-78E-0.5_THT
U2: AMS1117-3.3; SOT-223-3_TabPin2; JLCpart C2992570

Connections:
/3V3_BUS: A1.17 (3V3), A2.7 (3V3), C2.1, JP1.3 (B), JP2.3 (B), JP3.3 (B), JP4.3 (B), JP5.3 (B), JP6.3 (B), JP7.3 (B), JP8.3 (B), U2.2 (VO)
/5V_BUS: A1.27 (+5V), A2.10 (5V), C1.1, EC2.1, JP1.1 (A), JP2.1 (A), JP3.1 (A), JP4.1 (A), JP5.1 (A), JP6.1 (A), JP7.1 (A), JP8.1 (A), R1.2, R2.2, R3.2, R4.2, R5.2, R6.2, R7.2, R8.2, R9.2, R10.2, R11.2, R12.2, R13.2, R14.2, R15.2, R16.2, R17.2, R18.2, U1.3 (OUT), U2.3 (VI)
/SCL: A1.24 (A5), A2.12 (SCL), R2.1
/SCL_CH0: A2.32 (SCL_CH0), J1.3, J2.3, J3.3, J4.3, J5.3, R17.1
/SCL_CH1: A2.31 (SCL_CH1), J6.3, J7.3, J8.3, J9.3, J10.3, R9.1
/SCL_CH2: A2.30 (SCL_CH2), J11.3, J12.3, J13.3, J14.3, J15.3, R8.1
/SCL_CH3: A2.29 (SCL_CH3), J16.3, J17.3, J18.3, J19.3, J20.3, R7.1
/SCL_CH4: A2.28 (SCL_CH4), J21.3, J22.3, J23.3, J39.3, J40.3, R6.1
/SCL_CH5: A2.27 (SCL_CH5), J24.3, J25.3, J26.3, J33.3, J34.3, R5.1
/SCL_CH6: A2.26 (SCL_CH6), J27.3, J28.3, J29.3, J35.3, J36.3, R4.1
/SCL_CH7: A2.25 (SCL_CH7), J30.3, J31.3, J32.3, J37.3, J38.3, R3.1
/SDA: A1.23 (A4), A2.11 (SDA), R1.1
/SDA_CH0: A2.17 (SDA_CH0), J1.7, J2.2, J3.2, J4.7, J5.2, R18.1
/SDA_CH1: A2.18 (SDA_CH1), J6.2, J7.2, J8.2, J9.7, J10.7, R16.1
/SDA_CH2: A2.19 (SDA_CH2), J11.2, J12.2, J13.2, J14.7, J15.7, R15.1
/SDA_CH3: A2.20 (SDA_CH3), J16.2, J17.2, J18.2, J19.7, J20.7, R14.1
/SDA_CH4: A2.21 (SDA_CH4), J21.2, J22.2, J23.2, J39.7, J40.7, R13.1
/SDA_CH5: A2.22 (SDA_CH5), J24.2, J25.2, J26.2, J33.7, J34.7, R12.1
/SDA_CH6: A2.23 (SDA_CH6), J27.2, J28.2, J29.2, J35.7, J36.7, R11.1
/SDA_CH7: A2.24 (SDA_CH7), J30.2, J31.2, J32.2, J37.7, J38.7, R10.1
/VCC_CH0: J1.5, J2.4, J3.4, J4.5, J5.4, JP1.2 (C)
/VCC_CH1: J6.4, J7.4, J8.4, J9.5, J10.5, JP2.2 (C)
/VCC_CH2: J11.4, J12.4, J13.4, J14.5, J15.5, JP3.2 (C)
/VCC_CH3: J16.4, J17.4, J18.4, J19.5, J20.5, JP4.2 (C)
/VCC_CH4: J21.4, J22.4, J23.4, J39.5, J40.5, JP8.2 (C)
/VCC_CH5: J24.4, J25.4, J26.4, J33.5, J34.5, JP5.2 (C)
/VCC_CH6: J27.4, J28.4, J29.4, J35.5, J36.5, JP6.2 (C)
/VCC_CH7: J30.4, J31.4, J32.4, J37.5, J38.5, JP7.2 (C)
GND: A1.4 (GND), A1.29 (GND), A2.8 (GND), A2.9 (GND), C1.2, C2.2, EC1.2, EC2.2, J1.1, J2.1, J3.1, J4.1, J5.1, J6.1, J7.1, J8.1, J9.1, J10.1, J11.1, J12.1, J13.1, J14.1, J15.1, J16.1, J17.1, J18.1, J19.1, J20.1, J21.1, J22.1, J23.1, J24.1, J25.1, J26.1, J27.1, J28.1, J29.1, J30.1, J31.1, J32.1, J33.1, J34.1, J35.1, J36.1, J37.1, J38.1, J39.1, J40.1, J41.1, U1.2 (GND), U2.1 (GND)
unnamed: EC1.1, J41.2, U1.1 (IN)

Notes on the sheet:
RJ45 Sensor Connections
CH-3
I2C Bus Pullup Resistors
Bus I2C Header Pins
CH-2
Voltage Selection
CH-7
MCU
CH-1
CH-6
Should be left unpopulated but on board if required by total number of sensors
CH-4
Power Supply
CH-0
CH-5

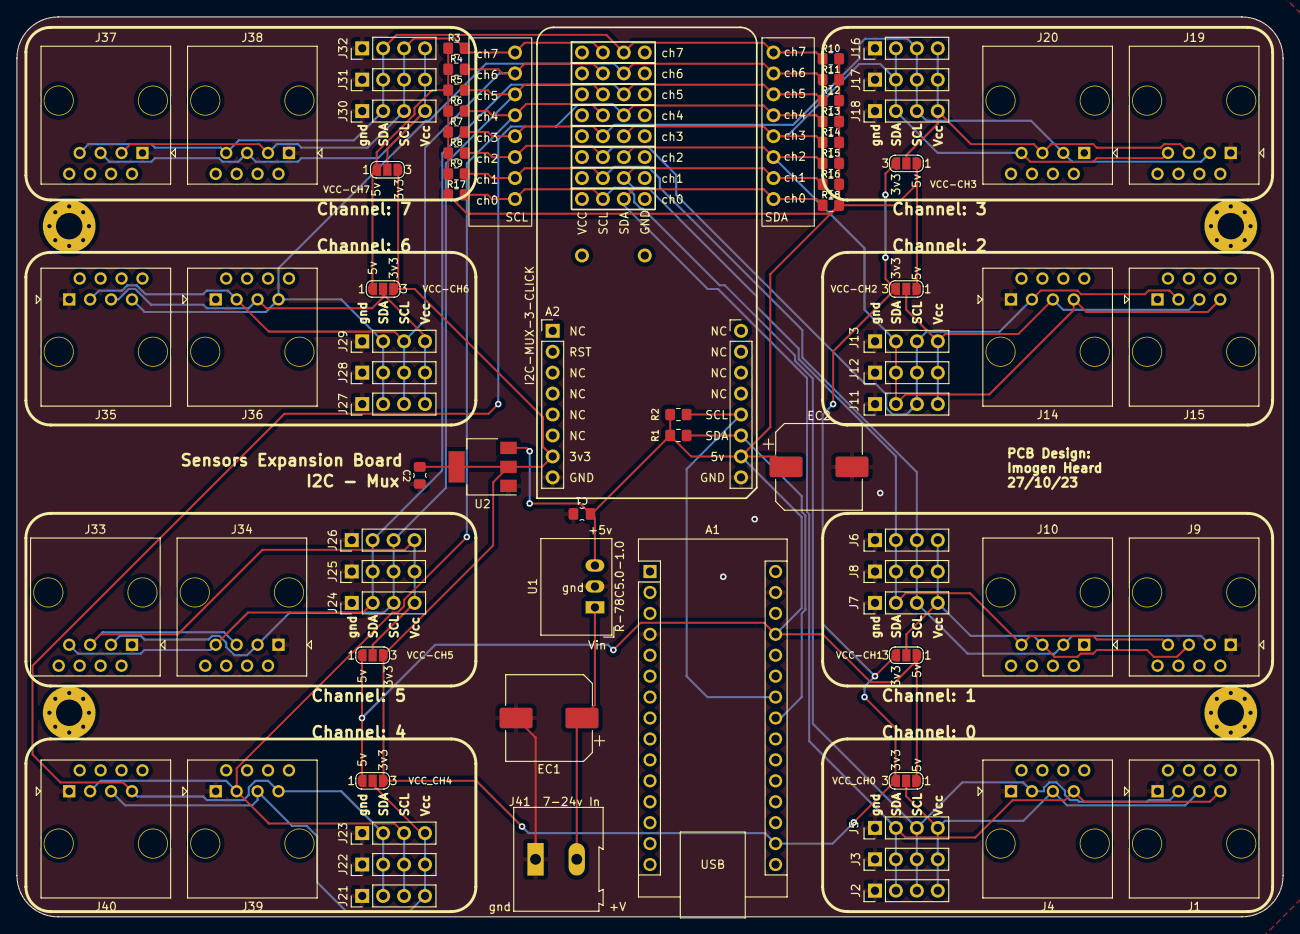
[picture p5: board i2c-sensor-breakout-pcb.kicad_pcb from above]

Board: 2 copper layers, 153.7 x 109.2 mm, 79 parts (0 on the bottom side), 30 nets.

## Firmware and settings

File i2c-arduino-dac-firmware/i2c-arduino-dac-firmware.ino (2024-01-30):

/* # European Project i2c Sensor Mux - MAIN


List of Sensors and Mux Channel Numbers
Mux 0 = i2c bus from nano
Mux 1 = Mux Module 1
Mux 2 = Mux Module 2 (for later expansion if required)
 
|No. |Sensor Name (system)  |	Sensor Type (model) |	Data Returned       |	Units                 |	Sample Rate  (Hz or every X seconds)| Mux.Channel  |
|--- |---                   |---                  |---                  |---                    |---                                  |---           |
| 1  | CD1                  | SEK-SCD41 - CO2     | CO2, Temp, Humidity | ppm/fraction, degC, % | 5 s                                 |  1.0         |
| 2  | CD2                  | SEK-SCD41 - CO2     | CO2, Temp, Humidity | ppm/fraction, degC, % | 5 s                                 |  1.1         |
| 3  | CD3                  | SEK-STC31 - CO2     | CO2                 | ppm/fraction          | 2 s  (Can work with 4s to match RHT)|  1.4         |  These might need to move channels
| 4  | CD4                  | SEK-STC31 - CO2     | CO2                 | ppm/fraction          | 2 s  (Can work with 4s to match RHT)|  1.5         |
| 5  | CD5                  | SEK-STC31 - CO2     | CO2                 | ppm/fraction          | 2 s  (Can work with 4s to match RHT)|  1.2         |
| 6  | CD6                  | SEK-STC31 - CO2     | CO2                 | ppm/fraction          | 2 s  (Can work with 4s to match RHT)|  1.3         |
| 7  | RHT3                 | SEK-SHT41I-AD1B     | Temp, Humidity      | degC, %               | 4 s                                 |  1.0         |
| 8  | RHT4                 | SEK-SHT41I-AD1B     | Temp, Humidity      | degC, %               | 4 s                                 |  1.1         |
| 9  | RHT5                 | SEK-SHT41I-AD1B     | Temp, Humidity      | degC, %               | 4 s                                 |  1.2         |
| 10 | RHT6                 | SEK-SHT41I-AD1B     | Temp, Humidity      | degC, %               | 4 s                                 |  1.3         |
| 11 | dP1                  | SDP810-125Pa        | diffPressure, Temp  | mBar, degC            | n/a                                 |  1.5         |
| 12 | dP2                  | SDP810-500Pa        | diffPressure, Temp  | mBar, degC            | n/a                                 |  1.6         |
| 13 | dP3                  | SDP810-500Pa        | diffPressure, Temp  | mBar, degC            | n/a                                 |  1.7         |
| 14 | Mux 1                | I2C MUX 3 click     | i2C Mux             | n/a                   | n/a                                 |  0.0         |
| 15 | Mux 2                | I2C MUX 3 click     | i2C Mux             | n/a                   | n/a                                 |  0.1  (change address)|


NOTES:
  - Issues found with SCD41 and STC31 operating on the same channel.
    - Moving Channels to Mitigate
    - Did not change anything
    - Changed power source to 3v3
    - Problem solved? For now! [x]


*/


// define the active sensors
bool CD1_ACTIVE = 1;
bool CD2_ACTIVE = 1;
bool CD3_ACTIVE = 1;
bool CD4_ACTIVE = 1;
bool CD5_ACTIVE = 1;
bool CD6_ACTIVE = 1;
bool RHT3_ACTIVE = 1;
bool RHT4_ACTIVE = 1;
bool RHT5_ACTIVE = 1;
bool RHT6_ACTIVE = 1;
bool dP1_ACTIVE = 1;
bool dP2_ACTIVE = 1;
bool dP3_ACTIVE = 1;




#include <Wire.h>
#include "i2c-utils.h"
#include "UI-utils.h"


#include <autoDelay.h>
autoDelay printDelay;
#define PRINT_DELAY_S 3


#define DEBUG true

// Create instances for each sensor
#include "SCD41.h"
SCD41 CD1("CD1");  // Create instance of SCD41 for CD1
SCD41 CD2("CD2");  // Create instance of SCD41 for CD2

#include "STC31.h"
STC31 CD3("CD3");  // Create instance of STC31 for CD3
STC31 CD4("CD4");  // Create instance of STC31 for CD4
STC31 CD5("CD5");  // Create instance of STC31 for CD5
STC31 CD6("CD6");  // Create instance of STC31 for CD6

#include "SHT41.h"
SHT41 RHT3("RHT3");  // Create instance of SHT41 for RHT3
SHT41 RHT4("RHT4");  // Create instance of SHT41 for RHT4
SHT41 RHT5("RHT5");  // Create instance of SHT41 for RHT5
SHT41 RHT6("RHT6");  // Create instance of SHT41 for RHT6

#include "SDP810.h"
SDP810 dP1("dP1");  // Create instance of SDP810 for dP1
SDP810 dP2("dP2");  // Create instance of SDP810 for dP2
SDP810 dP3("dP3");  // Create instance of SDP810 for dP3



void setup() {
  Serial.begin(19200);
  // Serial.println(F("\nSensor i2c Mux"));
  delay(50);
  setupMux();
  delay(40);
  // Serial.println("Begin Sensor Setup");

  // sensorMux.setPort(0); // Make sure this is set to the port you wish to scan
  //i2c_scanner(); // Use this section to find attached sensors
  // while (1){}

  sensorMux.setPort(0);  // Ensure that sensors with the same ID are not connected to the same port
  if (CD1_ACTIVE) { CD1.scd41_Setup(); }
  if (RHT3_ACTIVE) { RHT3.sht41_Setup(); }
  delay(40);

  sensorMux.setPort(1);  //
  if (CD2_ACTIVE) { CD2.scd41_Setup(); }
  if (RHT4_ACTIVE) { RHT4.sht41_Setup(); }
  delay(40);

  sensorMux.setPort(2);
  if (CD5_ACTIVE) { CD5.stc31_Setup(); }
  if (RHT5_ACTIVE) { RHT5.sht41_Setup(); }
  delay(40);

  sensorMux.setPort(3);
  if (CD6_ACTIVE) { CD6.stc31_Setup(); }
  if (RHT6_ACTIVE) { RHT6.sht41_Setup(); }
  delay(40);

  sensorMux.setPort(4);
  if (CD3_ACTIVE) { CD3.stc31_Setup(); }
  delay(40);
  sensorMux.setPort(5);
  if (CD4_ACTIVE) { CD4.stc31_Setup(); }
  if (dP1_ACTIVE) { dP1.sdp810_Setup(); }
  delay(40);

  sensorMux.setPort(6);
  if (dP2_ACTIVE) { dP2.sdp810_Setup(); }
  delay(40);

  sensorMux.setPort(7);
  if (dP3_ACTIVE) { dP3.sdp810_Setup(); }
  delay(40);

  // Unused Ports
  // printDataHeader();  // Data header tells user order of data returned via serial

  delay(100);
}



uint16_t numSamples = 0;

void loop() {

  if (printDelay.secondsDelay(PRINT_DELAY_S)) {  // now sensor sampling also happens at the slower rate of printDelay
    // Set up variables to gather all sensor data
    SCD41::scd41_Data CD1_data;  // Return types for SCD data
    SCD41::scd41_Data CD2_data;  // Return types for SCD data

    STC31::stc31_Data CD3_data;  // Return types for STC Data
    STC31::stc31_Data CD4_data;  // Return types for STC Data
    STC31::stc31_Data CD5_data;  // Return types for STC Data
    STC31::stc31_Data CD6_data;  // Return types for STC Data

    SHT41::sht41_Data RHT3_data;  // Return types for SHT Data
    SHT41::sht41_Data RHT4_data;  // Return types for SHT Data
    SHT41::sht41_Data RHT5_data;  // Return types for SHT Data
    SHT41::sht41_Data RHT6_data;  // Return types for SHT Data

    SDP810::sdp810_Data dP1_data;  // return types for SDP810 data
    SDP810::sdp810_Data dP2_data;  // return types for SDP810 data
    SDP810::sdp810_Data dP3_data;  // return types for SDP810 data


    // Data gathering methods
    // USER NOTE: change order here to set port for each sensor

    delay(10);
    sensorMux.setPort(0);  //  Change port address to 0 and read all sensors on 0
    delay(10);
    if (CD1_ACTIVE) { CD1_data = CD1.scd41_Loop(); }     // This only updates data ~ every 5 seconds
    if (RHT3_ACTIVE) { RHT3_data = RHT3.sht41_Loop(); }  //

    delay(10);
    sensorMux.setPort(1);  //  Change port address to 1 and read all sensors on 1
    delay(10);
    if (CD2_ACTIVE) { CD2_data = CD2.scd41_Loop(); }     // This only updates data ~ every 5 seconds
    if (RHT4_ACTIVE) { RHT4_data = RHT4.sht41_Loop(); }  //

    delay(10);
    sensorMux.setPort(2);  //  Change port address to 1 and read all sensors on 2
    delay(10);
    if (CD5_ACTIVE) { CD5_data = CD5.stc31_Loop(); }     //
    if (RHT5_ACTIVE) { RHT5_data = RHT5.sht41_Loop(); }  //

    delay(10);
    sensorMux.setPort(3);  //  Change port address to 1 and read all sensors on 3
    delay(10);
    if (CD6_ACTIVE) { CD6_data = CD6.stc31_Loop(); }     //
    if (RHT6_ACTIVE) { RHT6_data = RHT6.sht41_Loop(); }  //

    delay(10);
    sensorMux.setPort(4);
    delay(10);
    if (CD3_ACTIVE) { CD3_data = CD3.stc31_Loop(); }  //

    delay(10);
    sensorMux.setPort(5);
    delay(10);
    if (CD4_ACTIVE) { CD4_data = CD4.stc31_Loop(); }  //
    if (dP1_ACTIVE) { dP1_data = dP1.sdp810_Loop(); }

    delay(10);
    sensorMux.setPort(6);
    delay(10);
    if (dP2_ACTIVE) { dP2_data = dP2.sdp810_Loop(); }

    delay(10);
    sensorMux.setPort(7);
    delay(10);
    if (dP3_ACTIVE) { dP3_data = dP3.sdp810_Loop(); }

    // Unused Ports

    // Printing/transmitting data to serial output
    // if (printDelay.secondsDelay(PRINT_DELAY_S)) {   // moved this to also delay the sensor readings
    char printBuffer[32];  // all sensors share single print buffer

    if (numSamples < 0) {
      //skip printing the 0 sample for stability (disabled for now)
    } else {
      sprintf(printBuffer, "%03i:  ", numSamples);  // Print number of samples taken for tracking function (remove line if unneeded)
      Serial.print(printBuffer);

      if (CD1_ACTIVE) {
        char scd_tempBuffer[6];
        char scd_humidBuffer[6];
        dtostrf(CD1_data.temperature, 4, 2, scd_tempBuffer);
        dtostrf(CD1_data.humidity, 4, 2, scd_humidBuffer);
        //sprintf(printBuffer, "| SCD41: CO2: %4i ppm, Temperature: %s degC, Humidity: %s %% |", CD1_data.CO2, scd_tempBuffer, scd_humidBuffer);
        sprintf(printBuffer, "%s: %4i, %5s, %5s, ", CD1.ID, CD1_data.CO2, scd_tempBuffer, scd_humidBuffer);  // Just the Data
        Serial.print(printBuffer);
      }
      if (CD2_ACTIVE) {
        char scd_tempBuffer[6];
        char scd_humidBuffer[6];
        dtostrf(CD2_data.temperature, 4, 2, scd_tempBuffer);
        dtostrf(CD2_data.humidity, 4, 2, scd_humidBuffer);
        sprintf(printBuffer, "%s: %4i, %5s, %5s, ", CD2.ID, CD2_data.CO2, scd_tempBuffer, scd_humidBuffer);  // Just the Data
        Serial.print(printBuffer);
      }

      if (CD3_ACTIVE) {
        char stc_gasBuffer[6];
        char stc_tempBuffer[6];
        dtostrf(CD3_data.gasConcentration, 4, 2, stc_gasBuffer);
        dtostrf(CD3_data.gasTemperature, 4, 2, stc_tempBuffer);
        //sprintf(printBuffer, "| STC31: CO2: %s ppm, Temperature %s degC|", gasBuffer, stc_tempBuffer);  // Full UI printout
        sprintf(printBuffer, "%s: %5s, ", CD3.ID, stc_gasBuffer);  // just the data
        Serial.print(printBuffer);
      }
      if (CD4_ACTIVE) {
        char stc_gasBuffer[6];
        char stc_tempBuffer[6];
        dtostrf(CD4_data.gasConcentration, 4, 2, stc_gasBuffer);
        dtostrf(CD4_data.gasTemperature, 4, 2, stc_tempBuffer);
        //sprintf(printBuffer, "| STC31: CO2: %s ppm, Temperature %s degC|", gasBuffer, stc_tempBuffer);  // Full UI printout
        sprintf(printBuffer, "%s: %5s, ", CD4.ID, stc_gasBuffer);  // just the data
        Serial.print(printBuffer);
      }
      if (CD5_ACTIVE) {
        char stc_gasBuffer[6];
        char stc_tempBuffer[6];
        dtostrf(CD5_data.gasConcentration, 4, 2, stc_gasBuffer);
        dtostrf(CD5_data.gasTemperature, 4, 2, stc_tempBuffer);
        //sprintf(printBuffer, "| STC31: CO2: %s ppm, Temperature %s degC|", gasBuffer, stc_tempBuffer);  // Full UI printout
        sprintf(printBuffer, "%s: %5s, ", CD5.ID, stc_gasBuffer);  // just the data
        Serial.print(printBuffer);
      }
      if (CD6_ACTIVE) {
        char stc_gasBuffer[6];
        char stc_tempBuffer[6];
        dtostrf(CD6_data.gasConcentration, 4, 2, stc_gasBuffer);
        dtostrf(CD6_data.gasTemperature, 4, 2, stc_tempBuffer);
        //sprintf(printBuffer, "| STC31: CO2: %s ppm, Temperature %s degC|", gasBuffer, stc_tempBuffer);  // Full UI printout
        sprintf(printBuffer, "%s: %5s, ", CD6.ID, stc_gasBuffer);  // just the data
        Serial.print(printBuffer);
      }

      if (RHT3_ACTIVE) {
        char sht_tempBuffer[8];
        char sht_humidBuffer[8];
        dtostrf(RHT3_data.temperature, 4, 2, sht_tempBuffer);
        dtostrf(RHT3_data.humidity, 4, 2, sht_humidBuffer);
        //sprintf(printBuffer, "| SHT41: Temperature: %s degC, Humidity: %s %% |", sht_tempBuffer, sht_humidBuffer); // Full UI Printout
        sprintf(printBuffer, "%s: %5s, %5s, ", RHT3.ID, sht_tempBuffer, sht_humidBuffer);  // just the data
        Serial.print(printBuffer);
      }
      if (RHT4_ACTIVE) {
        char sht_tempBuffer[8];
        char sht_humidBuffer[8];
        dtostrf(RHT4_data.temperature, 4, 2, sht_tempBuffer);
        dtostrf(RHT4_data.humidity, 4, 2, sht_humidBuffer);
        //sprintf(printBuffer, "| SHT41: Temperature: %s degC, Humidity: %s %% |", sht_tempBuffer, sht_humidBuffer); // Full UI Printout
        sprintf(printBuffer, "%s: %5s, %5s, ", RHT4.ID, sht_tempBuffer, sht_humidBuffer);  // just the data
        Serial.print(printBuffer);
      }
      if (RHT5_ACTIVE) {
        char sht_tempBuffer[8];
        char sht_humidBuffer[8];
        dtostrf(RHT5_data.temperature, 4, 2, sht_tempBuffer);
        dtostrf(RHT5_data.humidity, 4, 2, sht_humidBuffer);
        //sprintf(printBuffer, "| SHT41: Temperature: %s degC, Humidity: %s %% |", sht_tempBuffer, sht_humidBuffer); // Full UI Printout
        sprintf(printBuffer, "%s: %5s, %5s, ", RHT5.ID, sht_tempBuffer, sht_humidBuffer);  // just the data
        Serial.print(printBuffer);
      }
      if (RHT6_ACTIVE) {
        char sht_tempBuffer[8];
        char sht_humidBuffer[8];
        dtostrf(RHT6_data.temperature, 4, 2, sht_tempBuffer);
        dtostrf(RHT6_data.humidity, 4, 2, sht_humidBuffer);
        //sprintf(printBuffer, "| SHT41: Temperature: %s degC, Humidity: %s %% |", sht_tempBuffer, sht_humidBuffer); // Full UI Printout
        sprintf(printBuffer, "%s: %5s, %5s, ", RHT6.ID, sht_tempBuffer, sht_humidBuffer);  // just the data
        Serial.print(printBuffer);
      }
      if (dP1_ACTIVE) {
        char sdp_diffPressureBuffer[8];
        char sdp_tempBuffer[8];
        dtostrf(dP1_data.diffPressure, 4, 2, sdp_diffPressureBuffer);
        dtostrf(dP1_data.temp, 4, 2, sdp_tempBuffer);
        sprintf(printBuffer, "%s: %5s, %5s, ", dP1.ID, sdp_diffPressureBuffer, sdp_tempBuffer);  // just the data
        Serial.print(printBuffer);
      }
      if (dP2_ACTIVE) {
        char sdp_diffPressureBuffer[8];
        char sdp_tempBuffer[8];
        dtostrf(dP2_data.diffPressure, 4, 2, sdp_diffPressureBuffer);
        dtostrf(dP2_data.temp, 4, 2, sdp_tempBuffer);
        sprintf(printBuffer, "%s: %5s, %5s, ", dP2.ID, sdp_diffPressureBuffer, sdp_tempBuffer);  // just the data
        Serial.print(printBuffer);
      }
      if (dP3_ACTIVE) {
        char sdp_diffPressureBuffer[8];
        char sdp_tempBuffer[8];
        dtostrf(dP3_data.diffPressure, 4, 2, sdp_diffPressureBuffer);
        dtostrf(dP3_data.temp, 4, 2, sdp_tempBuffer);
        sprintf(printBuffer, "%s: %5s, %5s, ", dP3.ID, sdp_diffPressureBuffer, sdp_tempBuffer);  // just the data
        Serial.print(printBuffer);
      }

      Serial.println();  // Send line return once all data has been sent
    }
    numSamples++;
  }
}

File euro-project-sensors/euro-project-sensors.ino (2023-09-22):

/*
 I2C Pin Definition:

 
SDA -> A4 -> Green
SCL -> A5 -> Yellow


 */

#include <Arduino.h>
#include <Wire.h>


#include <autoDelay.h>
autoDelay printDelay;
#define PRINT_DELAY_S 6


#include "SCD41-CO2-sensor.h"
#include "STC31-CO2-sensor.h"
#include "SHT41-HT-sensor.h"
#include "ACS70331-current-sensor.h"


void setup() {
  Serial.begin(115200);
  while (!Serial) {
    delay(100);
  }
  Serial.println("\nEuropean Project - i2c Sensor Interface");
  delay(1000);
  Wire.begin();
  scd41_Setup();
  stc31_Setup();
  sht41_Setup();

  // ACS70331_Setup();
}

//int countdown = 5;

bool sampleData = false;

void loop() {
  delay(1000);
  char printBuffer[64];  // all sensors share


  scd41_Data SCD41_data;
  char scd_tempBuffer[8];
  char humidBuffer[8];
  SCD41_data = scd41_Loop();  // This only updates data ~ every 5 seconds - now has global falg to identify when data has been updated

  stc31_Data STC31_data;
  char gasBuffer[8];
  char stc_tempBuffer[8];
 // STC31_data = stc31_Loop();

  sht41_Data SHT41_data;
  char sht_humidBuffer[8];
  char sht_tempBuffer[8];
  SHT41_data = sht41_Loop();





  if (scd41_DataReady) {  // only print data if sensor has new data
    sampleData = true;
  }

  if (printDelay.secondsDelay(PRINT_DELAY_S)) {
    if (sampleData) {
      dtostrf(SCD41_data.temperature, 4, 2, scd_tempBuffer);
      dtostrf(SCD41_data.humidity, 4, 2, humidBuffer);
      sprintf(printBuffer, "| SCD41: CO2: %4i ppm, Temperature: %s degC, Humidity: %s %% |", SCD41_data.CO2, scd_tempBuffer, humidBuffer);
      Serial.print(printBuffer);

      dtostrf(STC31_data.gasConcentration, 4, 2, gasBuffer);
      dtostrf(STC31_data.gasTemperature, 4, 2, stc_tempBuffer);
      sprintf(printBuffer, "| STC31: CO2: %s ppm, Temperature %s degC|", gasBuffer, stc_tempBuffer);
   ///   Serial.println(printBuffer);


      dtostrf(SHT41_data.temperature, 4, 2, sht_tempBuffer);
      dtostrf(SHT41_data.humidity, 4, 2, sht_humidBuffer);
      sprintf(printBuffer, "| SHT41: Temperature: %s degC, Humidity: %s %% |", sht_tempBuffer, sht_humidBuffer);
      Serial.println(printBuffer);


      //  countdown = 6;
      sampleData = false;
    }
  } else {
    // Just for debugging timings
    // Serial.print("Count: ");
    // Serial.println(countdown);
    //countdown--;
  }
}

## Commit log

2023-09-22 added all types of sensor to implementation
2023-09-28 getting i2c sensosrs working
2023-09-28 mux working, now making classes for each sensor, will improve useability
2023-09-29 dfgstarted working on main program using classes to create instances for different sensors
2023-09-29 Arduino firmware mostly completed
2023-10-02 issue with not reading sensor was power related not code
    [STC31.cpp]
2023-10-26 started PCB design
    [euro-project-sensors-pcb.kicad_pcb, euro-project-sensors-pcb.kicad_sch]
2023-10-30 PCB design Revision
    [euro-project-sensors-pcb-B_Cu.gbr, euro-project-sensors-pcb-B_Mask.gbr, euro-project-sensors-pcb-B_Paste.gbr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]
2024-01-10 Removed unnessisary serial prints
2024-01-22 adding SDP810 differential pressure sensor
2024-01-22 working on SDP910 sensor
2024-01-23 updated firmware to handle sdp810 differential pressure sensors
2024-01-24 Change repo to generic sensor outline
    [euro-project-sensors-pcb-B_Cu.gbr, euro-project-sensors-pcb-B_Mask.gbr, euro-project-sensors-pcb-B_Paste.gbr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]
